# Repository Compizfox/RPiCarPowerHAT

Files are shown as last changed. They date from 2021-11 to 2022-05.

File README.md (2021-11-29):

# RPiCarPowerHAT
Automotive power management HAT for Raspberry Pi

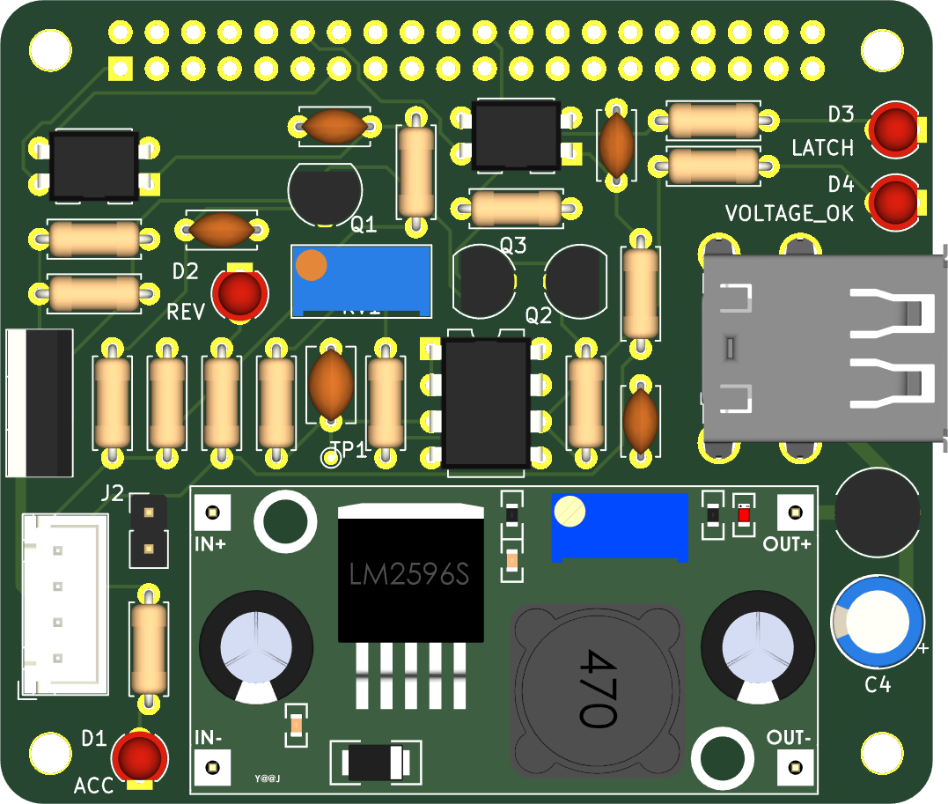
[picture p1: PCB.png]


The RPiCarPowerHAT is power management circuit for the Raspberry Pi in the form of a HAT. It is designed to to power a Raspberry Pi from 12 V available in a car. It uses a buck converter as a power supply and includes a power management circuit that powers the RPi by the car's permanent power (BAT), but can be switched by the car's accessory power (ACC) and subsequently latched by a GPIO pin from the RPi (inspired by [CarPiHat](https://github.com/gecko242/CarPiHat)). Hence, the RPi can be turned on using the car's ignition switch and latched on by the RPi itself so its power is not cut when the key is removed from the ignition. By releasing the latch, the RPi can then completely power itself down, in a software-defined way (for example, after a configurable time-out after removing the key from the ignition). This way, there is almost zero power draw when the RPi is turned off.

The RPiCarPowerHAT is designed to accept a LM2596 buck converter module, which can be found for less than €1. To alleviate coil whine and ripple, a post ripple filter consisting of an inductor and a capacitor (as recommended in [the datasheet](https://www.ti.com/lit/ds/symlink/lm2596.pdf)) is included in the HAT.

The board includes two opto-isolators for sensing 12 V, e.g. the car's ACC voltage and reversing voltage.

The board is fully THT for easy hand-soldering.

## Features
- Power supply: Uses a LM2596 buck converter module
  - Post ripple filter included
- Smart power management circuit:
  - The RPi is powered by the car's permanent 12 V power (BAT)
  - This is switched by a power MOSFET, which can be turned on by the car's ignition power (ACC) or latched from the RPi itself
  - Low-voltage cut-off to protect the car's battery from deeply discharging in case the RPi fails to release the latch
- 2 opto-isolated GPIO inputs, for e.g. sensing ACC voltage and reversing voltage
- 2 USB-A headers (power only), for e.g. powering a display
- A switched 12 V header for powering peripherals (powered when the RPi is)
- JST header with GND, BAT, ACC, and REV pins
- Status LEDs

## Circuit



## What you need to know
### GPIO pins (BCM numbering):
- Inputs:
  - BCM18 is pulled low when REV is high
  - BCM27 is pulled high wen ACC is high
- Outputs:
  - When BCM25 is pulled high from the RPi, it latches the power management circuit, causing it to stay on even when ACC is low.
  
### Tips
- Set the output voltage of the buck converter to 5.1 V by adjusting its trimpot before connecting the RPi, to prevent damaging the RPi by overvoltage.
- To set the low voltage threshold of the cut-off circuit, adjust trimpot RV1 on the board while measuring the voltage between TP1 and ground such that it reads 0.2 V at the desired threshold supply voltage.
- Do not connect a power supply to the RPi's own micro-USB input while using the power supply on this board.
- This does not fully comply with Raspberry Pi's HAT spec (it doesn't have an ID EEPROM onboard for GPIO autoconfiguration), so this is not an official Raspberry Pi® HAT.

## References

### KiCAD symbols, footprints, and models:

- [RPI_Hat_Template](https://github.com/devbisme/RPi_Hat_Template)
- [LM2596 module](https://grabcad.com/library/lm2596-module-for-kicad-1)
- [Stacked USB-A header](https://octopart.com/61400826021-w%C3%BCrth+elektronik-8917796)

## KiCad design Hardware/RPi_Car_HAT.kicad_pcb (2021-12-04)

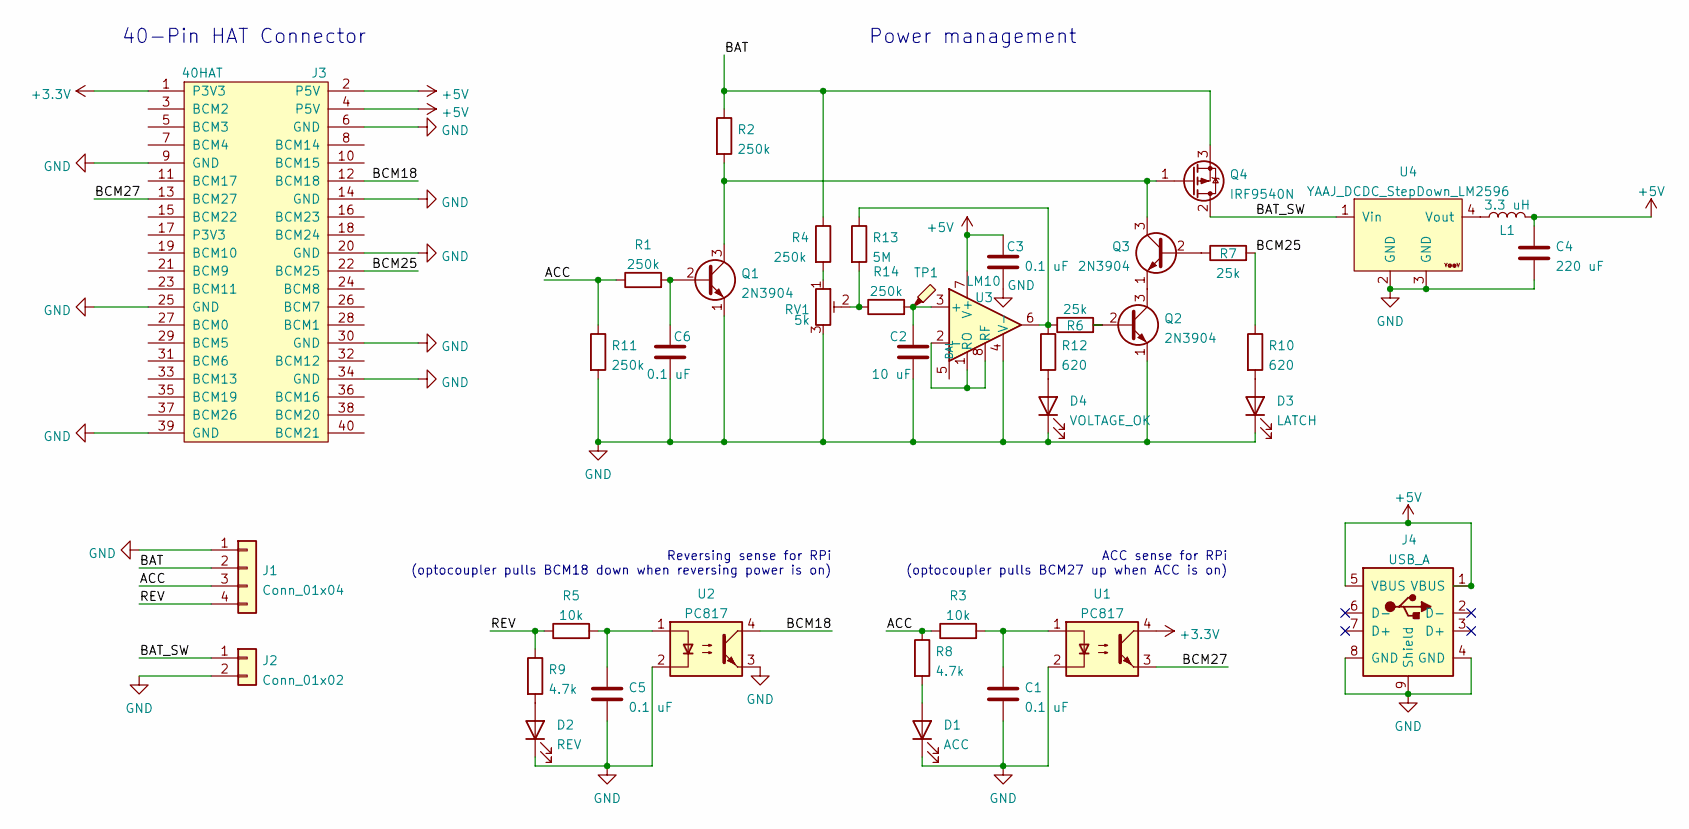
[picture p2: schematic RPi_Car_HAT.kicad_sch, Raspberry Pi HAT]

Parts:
C1, C3, C5, C6: 0.1 uF; C_Disc_D4.7mm_W2.5mm_P5.00mm
C2: 10 uF; C_Disc_D5.1mm_W3.2mm_P5.00mm
C4: 220 uF; CP_Radial_D6.3mm_P2.50mm
D1: ACC; LED_D3.0mm
D2: REV; LED_D3.0mm
D3: LATCH; LED_D3.0mm
D4: VOLTAGE_OK; LED_D3.0mm
J1: Conn_01x04; JST_XH_B4B-XH-A_1x04_P2.50mm_Vertical
J2: Conn_01x02; PinHeader_1x02_P2.54mm_Vertical
J3: 40HAT; PinSocket_2x20_P2.54mm_Vertical
J4: USB_A; USB_A_Wuerth_61400826021_Horizontal_Stacked
L1: 3.3 uH; L_Radial_D6.0mm_P4.00mm
Q1, Q2, Q3: 2N3904; TO-92_HandSolder
Q4: IRF9540N; TO-220-3_Vertical
R1, R2, R4, R11, R14: 250k; R_Axial_DIN0207_L6.3mm_D2.5mm_P7.62mm_Horizontal
R3, R5: 10k; R_Axial_DIN0207_L6.3mm_D2.5mm_P7.62mm_Horizontal
R6, R7: 25k; R_Axial_DIN0207_L6.3mm_D2.5mm_P7.62mm_Horizontal
R8, R9: 4.7k; R_Axial_DIN0207_L6.3mm_D2.5mm_P7.62mm_Horizontal
R10, R12: 620; R_Axial_DIN0207_L6.3mm_D2.5mm_P7.62mm_Horizontal
R13: 5M; R_Axial_DIN0207_L6.3mm_D2.5mm_P7.62mm_Horizontal
RV1: 5k; Potentiometer_Bourns_3296W_Vertical
TP1: TestPoint_Probe; TestPoint_THTPad_D1.0mm_Drill0.5mm
U1, U2: PC817; DIP-4_W7.62mm
U3: LM10; DIP-8_W7.62mm
U4: YAAJ_DCDC_StepDown_LM2596

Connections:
+3V3: J3.1 (P3V3), U1.4
+5V: C3.1, C4.1, J3.2 (P5V), J3.4 (P5V), J4.1 (VBUS), J4.5 (VBUS), L1.2, U3.7 (V+)
/ACC: J1.3, R1.1, R3.1, R8.1, R11.1
/BAT: J1.2, Q4.3 (S), R2.1, R4.1
/BAT_SW: J2.1, Q4.2 (D), U4.1 (Vin)
/BCM18: J3.12 (BCM18), U2.4
/BCM25: J3.22 (BCM25), R7.2, R10.1
/BCM27: J3.13 (BCM27), U1.3
/REV: J1.4, R5.1, R9.1
GND: C1.2, C2.2, C3.2, C4.2, C5.2, C6.2, D1.1 (K), D2.1 (K), D3.1 (K), D4.1 (K), J1.1, J2.2, J3.6 (GND), J3.9 (GND), J3.14 (GND), J3.20 (GND), J3.25 (GND), J3.30 (GND), J3.34 (GND), J3.39 (GND), J4.4 (GND), J4.8 (GND), J4.9 (Shield), Q1.1 (E), Q2.1 (E), R11.2, RV1.3, U1.2, U2.2, U2.3, U3.4 (V-), U4.2 (GND), U4.3 (GND)
unnamed: C1.1, R3.2, U1.1
unnamed: C2.1, R14.2, TP1.1, U3.3 (+)
unnamed: C5.1, R5.2, U2.1
unnamed: C6.1, Q1.2 (B), R1.2
unnamed: D1.2 (A), R8.2
unnamed: D2.2 (A), R9.2
unnamed: D3.2 (A), R10.2
unnamed: D4.2 (A), R12.2
unnamed: L1.1, U4.4 (Vout)
unnamed: Q1.3 (C), Q3.3 (C), Q4.1 (G), R2.2
unnamed: Q2.2 (B), R6.2
unnamed: Q2.3 (C), Q3.1 (E)
unnamed: Q3.2 (B), R7.1
unnamed: R4.2, RV1.1
unnamed: R6.1, R12.1, R13.1, U3.6
unnamed: R13.2, R14.1, RV1.2
unnamed: U3.1 (RO), U3.2 (-), U3.8 (RF)

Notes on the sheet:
40-Pin HAT Connector
Reversing sense for RPi (optocoupler pulls BCM18 down when reversing power is on)
Power management
ACC sense for RPi (optocoupler pulls BCM27 up when ACC is on)

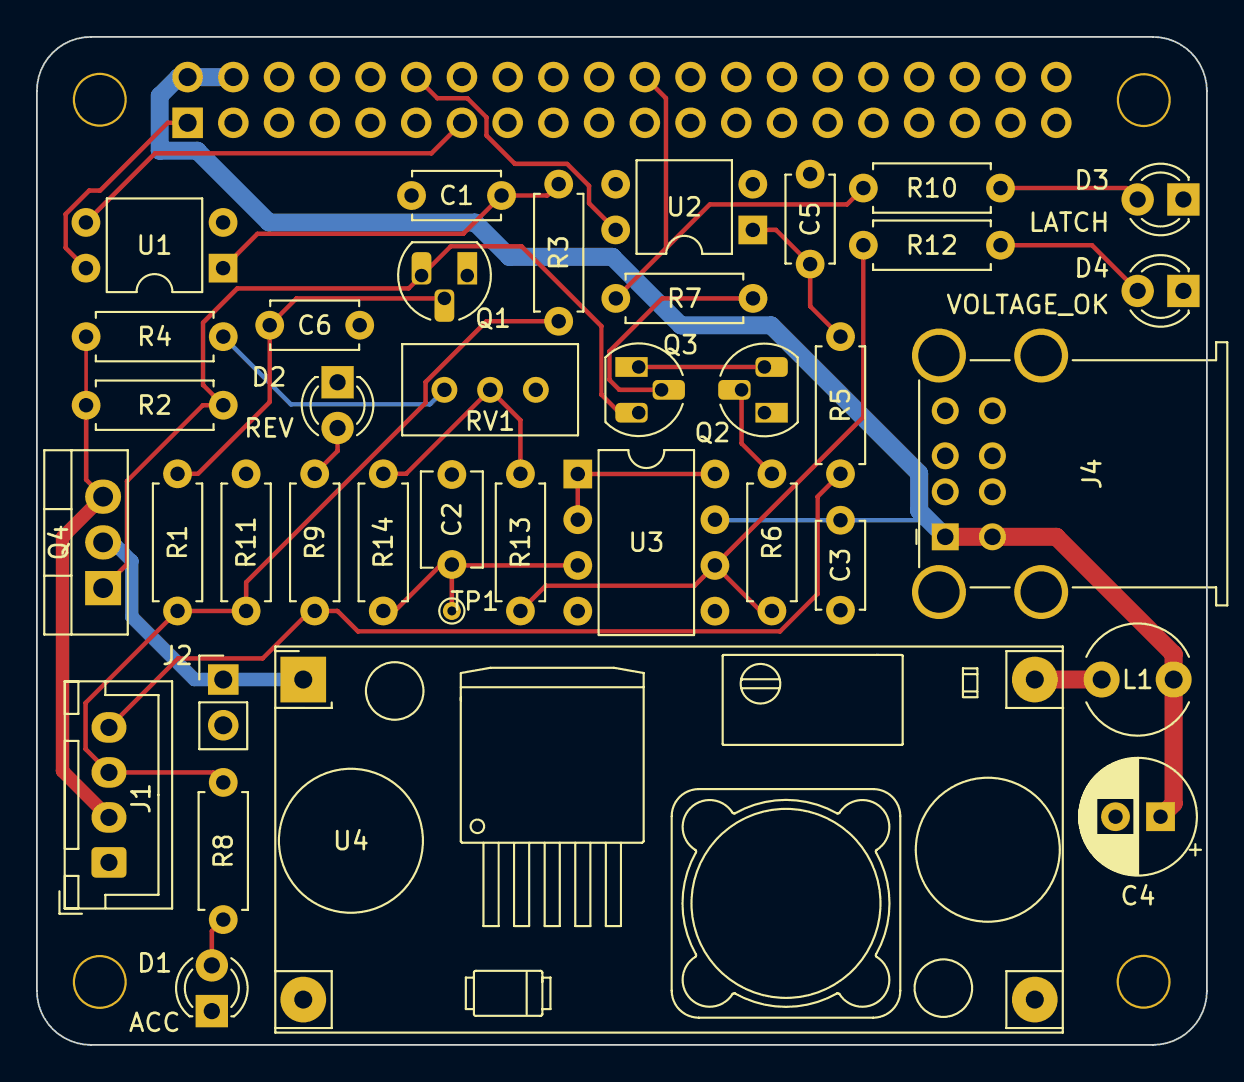
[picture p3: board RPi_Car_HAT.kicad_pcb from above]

Board: 2 copper layers, 65.0 x 56.0 mm, 43 parts (1 on the bottom side), 27 nets.

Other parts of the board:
H1, H2, H3, H4: 3mm_Mounting_Hole; NPTH_3mm_ID

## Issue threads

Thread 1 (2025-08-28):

Kicad files do not match Schematic.svg and PCB.png

KBC1950, 2025-08-28:
RPi_Car_HAT.kicad_sch does not match schematic.svg, emitter of Q1 does not go to GND. Therefore RPi_Car_HAT.kicad_pcb does not match PCB.png and circuit does not work..

Compizfox, 2025-08-28:
This was an intentional change in 32efec27a2ba4a602edbb2af9725aed434bd226d. The idea is to put the ACC trigger behind the low-voltage cutoff, so that the RPi turns off when e.g. the key is left in the ignition or ACC is high for some other reason, and the battery voltage is too low.

KBC1950, 2025-08-28:
That may bethe thought but with U3 being powered by +5V its output is low when U4 has noinput, ie when supply to Raspberry Pi is off. This means Q2 is off andtherefore there is no GND for Q1 to ever turn on. I built the HAT as per theKicad files and the only way I could get it to switch on was to move power to U3from +5V to BAT. I have not done any further testing with regards to lowvoltage cutoff.
RegardsKevin Coleman
    On Friday 29 August 2025 at 07:08:19 am AEST, Lars Veldscholte ***@***.***> wrote:

 Compizfox left a comment (Compizfox/RPiCarPowerHAT#1)
This was an intentional change in 32efec2. The idea is to put the ACC trigger behind the low-voltage cutoff, so that the RPi turns off when e.g. the key is left in the ignition or ACC is high for some other reason, and the battery voltage is too low.

—
Reply to this email directly, view it on GitHub, or unsubscribe.
You are receiving this because you authored the thread.Message ID: ***@***.***>

Compizfox, 2025-08-29:
Ah, I see, you're right. That's an oversight on my part. Thanks for reporting!

I have reverted the commit.

Closed 2025-08-29.

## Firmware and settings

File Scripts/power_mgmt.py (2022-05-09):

import RPi.GPIO as GPIO
from time import sleep
from subprocess import call

# Pin numbers (BCM numbering)
PIN_ACC = 27
PIN_LATCH = 25

INTERVAL = 10          # s
TIMEOUT_ACC_DOWN = 600 # s

GPIO.setmode(GPIO.BCM)
GPIO.setup(PIN_ACC, GPIO.IN)
GPIO.setup(PIN_LATCH, GPIO.OUT, initial=GPIO.HIGH)

print("Latched power.")

acc_low_for_seconds = 0;

while True:
    sleep(INTERVAL)
    if GPIO.input(PIN_ACC) == 0:
        print("ACC low for " + str(acc_low_for_seconds) + " s")
        acc_low_for_seconds += INTERVAL
        if acc_low_for_seconds > TIMEOUT_ACC_DOWN:
            print("Powering off")
            call("sudo shutdown -h now", shell=True)
    else:
        acc_low_for_seconds = 0

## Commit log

2021-12-04 Low voltage cut-off: add hysteresis, increase RC-time
    [RPi_Car_HAT.kicad_pcb, RPi_Car_HAT.kicad_sch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]
2023-12-05 Put ACC trigger behind low voltage cut-off, update to new KiCAD version
    [RPi_Car_HAT-B_Cu.gbl, RPi_Car_HAT-B_Mask.gbs, RPi_Car_HAT-B_Silkscreen.gbo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]
2025-08-29 Revert "Put ACC trigger behind low voltage cut-off, update to new KiCAD version"
    This reverts commit 32efec27a2ba4a602edbb2af9725aed434bd226d.
    [RPi_Car_HAT-NPTH-drl_map.dxf, RPi_Car_HAT-PTH-drl_map.dxf, RPi_Car_HAT.kicad_pcb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]

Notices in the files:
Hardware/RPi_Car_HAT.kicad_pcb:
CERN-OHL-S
